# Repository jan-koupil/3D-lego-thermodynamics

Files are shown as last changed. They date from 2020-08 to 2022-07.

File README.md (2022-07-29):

# LEGO-based Thermodynamics teaching set - Total and partial differentials

This repository contains OpenSCAD sources to generate tiles for hands-on teaching thermodynamics (integration over d*W*, d*Q*, d*U*).

The tile sizes are of standard Duplo brick, they can be mounted on top of Duplo or Lego bricks. The slope of the top surface is calculated to fit the Lego dimension and connect to neighbouring brick (if chosen correctly).

## Requirements
* Download file ``roundedcube.scad`` from https://danielupshaw.com/openscad-rounded-corners/ and place to the ``vendor`` subdirectory
* Download Doblo factory from http://edutechwiki.unige.ch/en/Doblo_factory (this repo used version 2.4) and place to ``DobloFactory`` subdirectory under the ``vendor``

## Generating the tiles
* Comment/uncomment lines in ``cmdline_tile.scad`` to select correct values of ``midHeight`` and ``slopeN`` for your tile set choice.
  * Create a single tile at given coordinates, e.g. [6;3] by calling ``OpenSCAD_executable" -o stl\tile_6_3.stl -D "x=6" -D "y=3" cmdline_tile.scad`` (on Windows typically use ``"c:\Program Files\OpenSCAD\openscad.com"`` as executable or replace it with your version for other systems)
  * Or create a full set of tiles by calling the ``make_tiles.cmd`` (Windows only)

## The 1.5-high tile
To fit neatly, some tiles require a 1.5-standard height spacer below. Its source is the ``one_and_half_plate.scad`` file.

## Customization
These tiles had been tuned for a single and specific 3D printer (as usual). You might find them perfectly fitting to your LEGO base - or not fitting at all. You can customize all parameters in the ``config.scad`` file, namely

* ``baseType`` - change the underlying LEGO-like tile type (see file for possible values, the difference is in the shape of bottom nops and supports of top plate)
* dimensions of the brick - valid only for baseTypes other than ``"doblo-factory"``
* The bricks are rounded and calculated for a specific layer height and nozzle width, don't forget to update these if using different printer.

## STLs

If you just want the STLs without customization, all can be donwloaded at https://www.thingiverse.com/thing:5444315

## Printed tiles

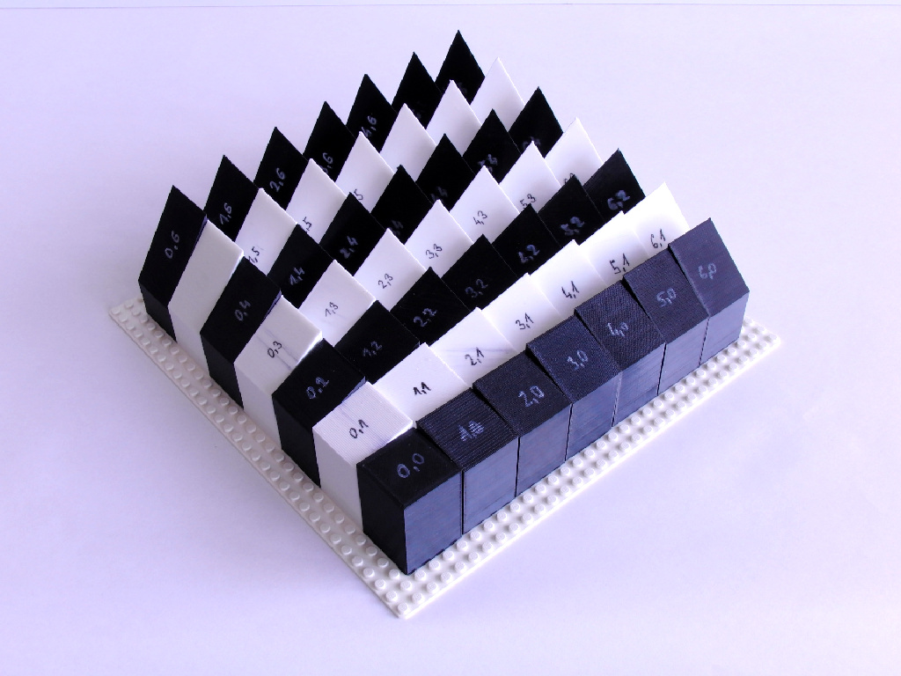
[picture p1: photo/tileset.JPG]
Full set of tiles (dQ)


Full set of d*Q* tiles on a plate, without supporting bricks

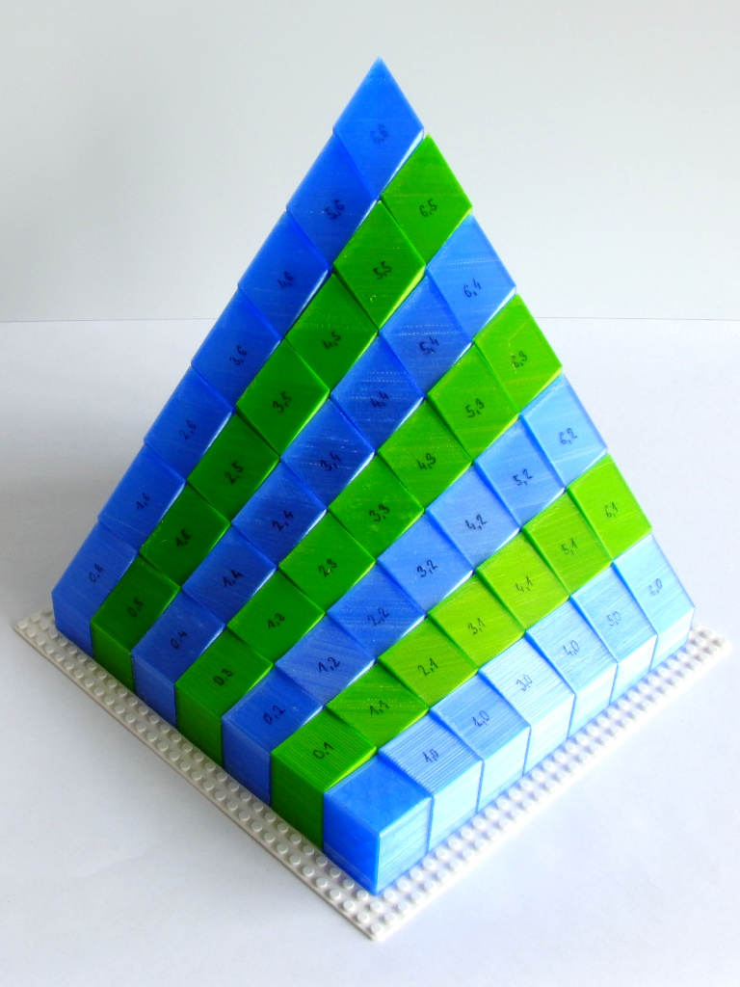
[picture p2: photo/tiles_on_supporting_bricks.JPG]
Full set of tiles (dU)


Full set of d*U* tiles on a plate, supported by regular LEGO/SUPLO bricks to connect smoothly

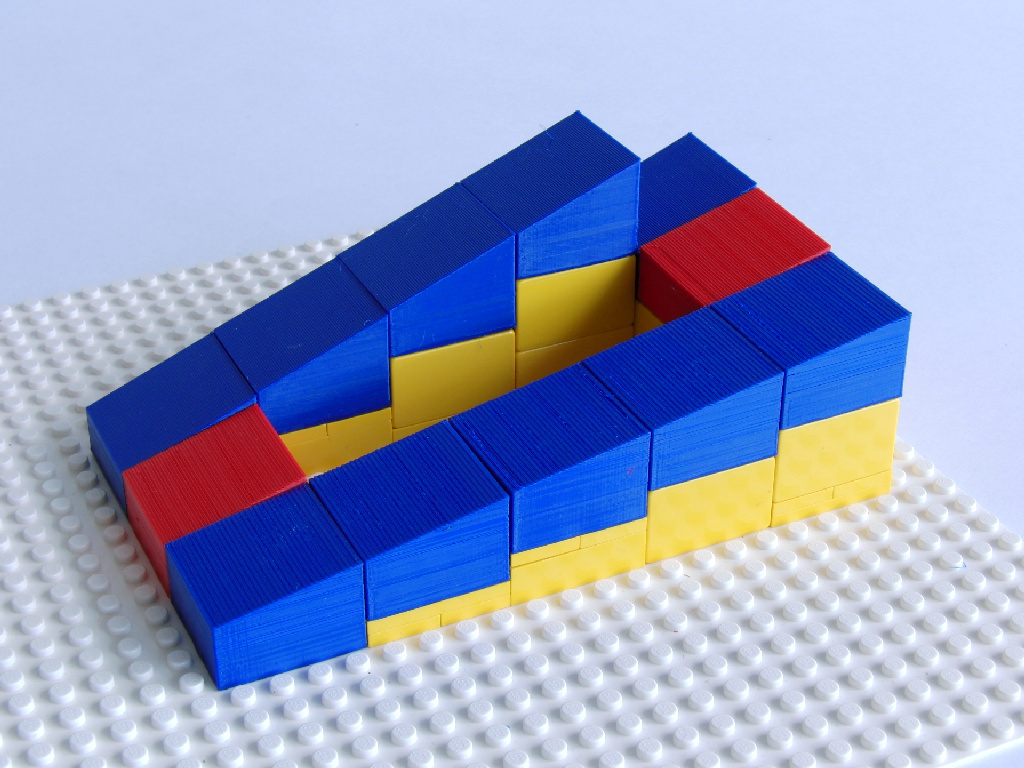
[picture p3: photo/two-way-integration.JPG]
Two ways of integration Two ways of integration (dW)


Two ways of integration (d*W*) over two paths (ideal gas, isobaric first and isothermic and vice versa).

## License

This work is licensed under a
[Creative Commons Attribution-NonCommercial-ShareAlike 4.0 International License][cc-by-nc-sa].

[][cc-by-nc-sa]

[cc-by-nc-sa]: http://creativecommons.org/licenses/by-nc-sa/4.0/
[cc-by-nc-sa-image]: https://licensebuttons.net/l/by-nc-sa/4.0/88x31.png
[cc-by-nc-sa-shield]: https://img.shields.io/badge/License-CC%20BY--NC--SA%204.0-lightgrey.svg

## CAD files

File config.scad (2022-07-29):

$fn = 30;

baseType = "lego-x";
// Allowed values are "doblo-factory", "duplo", "lego-x" and "lego-o"

play = 0.15; // this is reduced on each side of the brick from the base width 
// to make space for neighbouring cube
baseDim = 8; // this is lego base dimension

baseWidth = 4 * baseDim - 2 * play;
plateHeight = 3 * 3.2 - 0 * play;

wall = 1.35; //wall thickness - lego original value 1.6
ceiling = 1.4; //ceiling thickness - lego original value 1.6

layerHeight = 0.2; //print layer height
nozzleWidth = 0.4; //print nozzle width

// creates brim on real outside only, instead of slicer
brimWidth = 3;
brimThickness = 0; // set here, or leave 0 and use your slicer settings

//nop dimensions - for the 0.5 height tiles
nopDiameter = 4.95;//original value is 4.8
nopHeight = 1.9;//original value is 1.7

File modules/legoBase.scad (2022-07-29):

use <helpers.scad>;

module legoBase (
    pattern = "X", //either "X" or "O"
    baseWidth,
    plateHeight,
    play,
    wall, //wall thickness
    ceiling, //ceiling thickness   
    layerHeight, //print layer height
    nozzleWidth //print nozzle width
) {

    w = baseWidth / 2; // halfwidth
    baseDim = 8; // base lego dimension
    epsilon = 0.05;

    // each inner barrel
    // innerR = 5 / 2; // original lego value
    innerR = 5 / 2;
    // outerR = 6.6 / 2; // original lego value
    outerR = 6.3 / 2;

    innerWall = 1;     // inner wall thickness

    // walls
    make_ring_of(w, 4)
        wall();

    // ceiling
    color("green", 0.2)
        translate([-w, -w, -ceiling + plateHeight]) 
            cube([baseWidth, baseWidth, ceiling]);      
 

    // inner barrels
    if (pattern == "O") {
        color("lime", 0.6) {
            for(dx = [-1 : 1 : 1]){
                for(dy = [-1 : 1 : 1]){
                    translate([dx,dy,0] * baseDim)
                        barrel();
                }
            }
        }
    } else if (pattern == "X") {
 
        color("lime", 0.6) {
            barrel();
            turnAround(4) {
                translate([baseDim, baseDim, 0]) 
                    barrel();
            }
        }

        color("blue", 0.3) {
            turnAround(4) 
            {
                translate([-w, -innerWall / 2, 0])
                    cube([w - innerR, innerWall, plateHeight - epsilon]);
            }
        }

    } else {  
        echo ("Invalid value for pattern, choose \"X\" or \"O\"'");
    }

    // ceiling grating
    color("brown") {
        ceilingLogs(1);
        rotate([0, 0, 90])
            ceilingLogs(2);
    }

    module ceilingLogs(level) {
        translate([0, 0, plateHeight - ceiling - level * layerHeight]) {
            rotate([0, 0, 45])        
                cube([2 * nozzleWidth, sqrt(2) * (baseWidth - 4 * nozzleWidth), level * layerHeight], center = true);

            translate([baseWidth / 4, baseWidth / 4, 0])
                rotate([0, 0, 45])        
                    cube([2 * nozzleWidth, sqrt(2) / 2 * (baseWidth - 4 * nozzleWidth), level * layerHeight], center = true);

            translate([-baseWidth / 4, -baseWidth / 4, 0])
                rotate([0, 0, 45])        
                    cube([2 * nozzleWidth, sqrt(2) / 2 * (baseWidth - 4 * nozzleWidth), level * layerHeight], center = true);
        }
    }
    // turnAround(2) {
    //     for(dx = [-1 : 1 : 1]){
    //         translate([-nozzleWidth + dx * baseDim, -w, plateHeight - ceiling - 2 * layerHeight])
    //             cube([2 * nozzleWidth, baseWidth, 2 * layerHeight]);
    //     }
    // }
    // turnAround(2) {
    //     for(dx = [-1 : 1 : 1]){
    //         rotate([0,0,90])
    //             translate([-nozzleWidth + dx * baseDim, -w, plateHeight - ceiling - layerHeight])
    //                 cube([2 * nozzleWidth, baseWidth, layerHeight]);
    //     }
    // }        

    module wall() {    
        color("red", 0.2)
        translate([-w, 0, 0])
        cube([baseWidth, wall, plateHeight - epsilon]);
    }      

    module barrel() {
        difference() {
            cylinder(r1 = outerR, r2 = outerR, h = plateHeight - epsilon);
            translate([0, 0, -epsilon])
                cylinder(r1 = innerR, r2 = innerR, h = plateHeight + 2 * epsilon);
        }    
    }       
}

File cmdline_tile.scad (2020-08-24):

// expects parameters x and y element of <0,6>
// example use: "c:\Program Files\OpenSCAD\openscad.com" -o stl\tile_6_3.stl -D "x=6" -D "y=3" cmdline_tile.scad

include <config.scad>;
use <modules\tile_module.scad>;

x=0; y=0; //magic code, only to initialize

/* dQ */
// midHeight = 38;
// slopeN = [-95 / 12 * y, -57 / 12 * x, 32];

/* dU */
// midHeight = 29;
// slopeN = [-57 / 12 * y, -57 / 12 * x, 32];

/* dW */
midHeight = 9.4;
slopeN = [-19 / 6 * y, 0, 32];

//tile (n = slopeN, h = midHeight, brimWidth = brimWidth, brimThickness = brimThickness);
tile (
    n = slopeN, 
    h = midHeight, 
    baseWidth = baseWidth,
    plateHeight = plateHeight,
    baseType = baseType,
    play = play, 
    wall = wall,
    ceiling = ceiling,
    layerHeight = layerHeight,
    nozzleWidth = nozzleWidth,
    brimWidth = brimWidth, 
    brimThickness = brimThickness
);

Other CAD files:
one_and_half_plate.scad
modules/baseplate.scad
modules/duploBase.scad
modules/helpers.scad
modules/tile_module.scad
tile_demo.scad

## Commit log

2020-04-13 First file
    [jednicka.scad]
2020-04-13 added readme for vendor list
    [jednicka.scad]
2020-06-24 slope defined by normal vector
    [dilek.scad]
2020-06-24 modularize the tile
    [dilek.scad, jednicka.scad, tile.scad]
2020-06-24 finalize module and add brim creation
    [tile.scad, tile_module.scad]
2020-06-24 create definitions file and tile distributing function
    [tile_definitions.scad, tile_demo.scad, tile_set.scad]
2020-06-24 add comments to definitions, increase the number of arcs
    [tile_definitions.scad, tile_set.scad]
2020-08-02 Use real formula to calculate definitions (the html/js), do it
    [tile_definitions.scad, tile_set.scad, tile_set_dQ_v_pV_6z6.stl]
2020-08-02 update gitignore
    [tile_set_dQ_v_pV_6z6.stl]
2020-08-14 change plate, vector is now for dU
    [cmdline_tile.scad, placka.scad, placka2.scad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]
2020-08-14 split to modules
    [baseplate.scad, cmdline_tile.scad, config.scad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]
2020-08-16 Enable function literals in command line
    [cmdline_tile.scad, config.scad, legoBase.scad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]
2020-08-24 Seal parameters to config and commandline
    [cmdline_tile.scad, config.scad, legoBase.scad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]
2022-07-29 Update config values
    [config.scad, legoBase.scad]
2022-07-29 Add 1.5 plate
    [one_and_half_plate.scad]
2022-07-29 Add readme/documentation
    [config.scad]
